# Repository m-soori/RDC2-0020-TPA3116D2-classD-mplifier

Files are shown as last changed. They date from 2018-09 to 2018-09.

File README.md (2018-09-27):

<p><a href="https://static.chipdip.ru/lib/954/DOC002954994.jpg" class="galery">Схема</a></p>

<p>Усилитель НЧ собран на микросхеме TPA3116D2.</p>
<p><a href="https://static.chipdip.ru/kits/9000398391/sh.png" class="galery">Схема</a></p>
<h2>Технические характеристики.</h2>
<p>Мощность на нагрузке 4 Ом. при U пит. 21В. – 2 x 50 Вт. (BTL), 100 Вт. (PBTL)<br/>Уровень сигнала на входе. - 0,8 … 2В.<br/>Отношение сигнал/шум. - 102 dB<br/>Коэффициент гармоник на половине мощности 25Вт. -  0,1%<br/>Напряжение питания – 4,5 В … 26 В.</p>
<p>Схема позволяет включать микросхему в двух режимах: </p>
<p>1. Мостовой BTL. В этом включении можно получить 2 канала по 50 Вт.<br/>2. Параллельно – мостовой (PBTL). Так как в этом режиме два канала BTL включены ещё и параллельно, то на выходе получаем один канал с удвоенной мощностью – 100 Вт.</p>
<p>На схемах ниже показаны все необходимые изменения для обоих режимов. </p>
<p>1. Подготовка платы для работы в мостовом режиме. Стерео 50 Вт.<br/>Собранный усилитель работает в мостовом режиме. Но если вы подаете на него сигнал по не симметричной линии, установите перемычки P7 и P12. Больше никаких перемычек устанавливать не надо. </p>
<p>2. Подготовка платы для работы в параллельно-мостовом режиме. Один канал 100 Вт.<br/>Установите перемычки P14, P15 и соедините перемычкой выходы усилителя P3 с P4 и P8 с P11.<br/>Теперь ваш усилитель будет работать в параллельно-мостовом режиме и выдавать 100 Вт.  Громкоговоритель подключайте к P6 и P8. Сигнал подавайте на вход правого канала.</p>
<p>Режим BTL</p>
<p><a href="https://static.chipdip.ru/kits/9000398391/BTL.png" class="galery">Схема BTL</a></p>
<p>Режим PBTL</p>
<p><a href="https://static.chipdip.ru/kits/9000398391/PBTL.png" class="galery">Схема PBTL</a></p>
<p>Подбором резисторов R5 и R8 можно подобрать уровень усиления и входное сопротивление, а также перевести усилитель в режимы ведущего (master) или ведомого (slave)</p>
<p><a href="https://static.chipdip.ru/kits/9000398391/tabR.png" class="galery">Настройка</a></p>
<p>Усилитель имеет очень высокий КПД > 90%, поэтому он не очень требователен к теплоотводу. В качестве радиатора можно использовать, <a href="/product0/9000398392" class="link">например этот</a>. Форма, крепежные отверстия и размеры, которого сделаны специально для этого модуля. К тому же он имеет золотое покрытие, что внешне очень привлекательно.</p>
<p>Радиатор</p>
<p><a href="https://static.chipdip.ru/kits/9000398391/RDC1-0021.jpg" class="galery">RDC1-0021</a></p>
<p>Это открытый проект! Лицензия, под которой он распространяется – <a href="https://creativecommons.org/licenses/by-sa/3.0/"  class="link">Creative Commons - Attribution - Share Alike</a> license.</p>

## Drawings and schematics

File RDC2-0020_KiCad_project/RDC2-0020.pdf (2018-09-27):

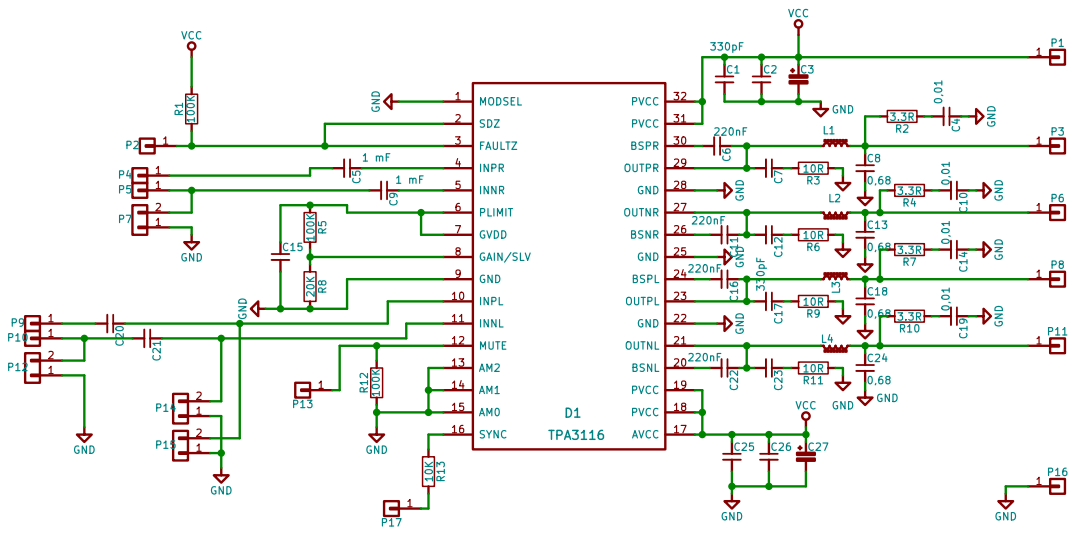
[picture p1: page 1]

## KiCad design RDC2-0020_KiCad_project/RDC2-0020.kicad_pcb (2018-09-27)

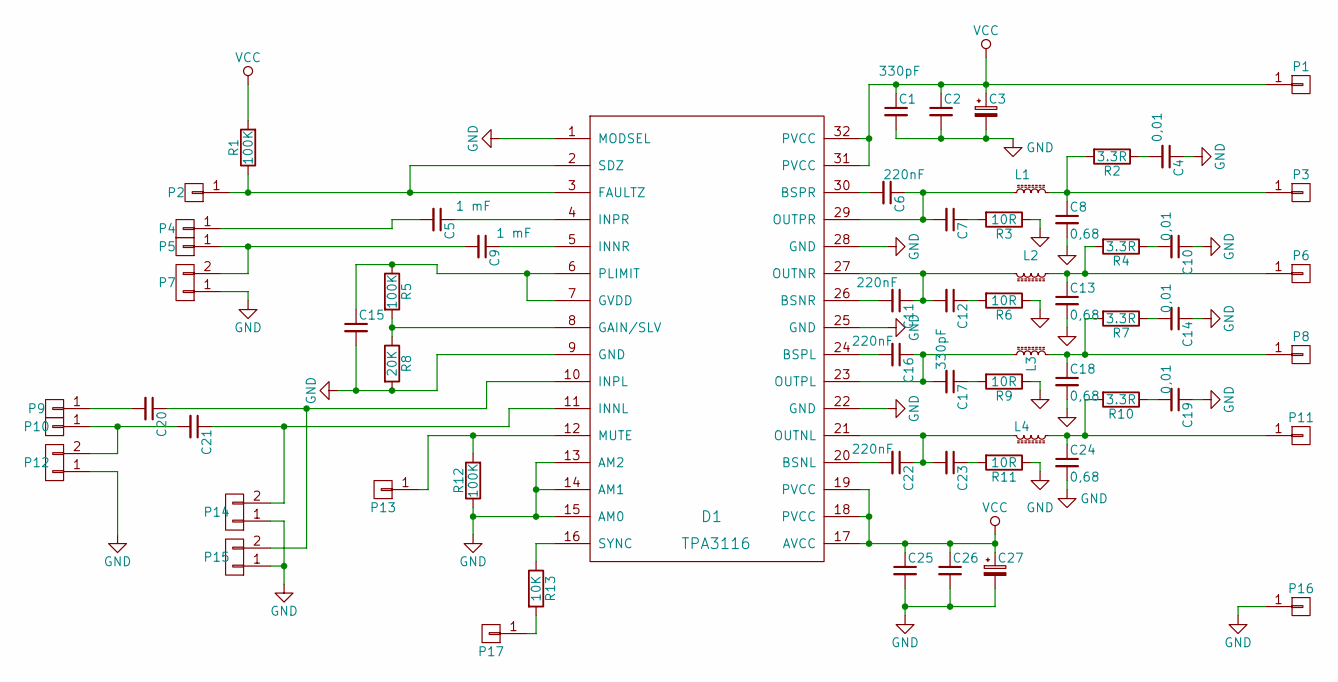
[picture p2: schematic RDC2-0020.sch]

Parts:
C1, C7, C12, C17, C23, C25: 330pF; C_1206
C2, C26: 0,1; C_0603
C3: 220mF; C_Radial_D8_L11.5_P3.5
C4, C10, C14, C19: 0,01; C_0805
C5, C9: 1 mF; C_0603
C6, C11, C16, C22: 220nF; C_0805
C8, C13, C18, C24: 0,68; C_1206
C15: C_Small; C_0805
C20, C21: C_Small; C_0603
C27: 220pF; C_Radial_D8_L11.5_P3.5
D1: TPA3116; TSSOP32
L1, L2, L3, L4: L_Core_Ferrite_Small; IND_12x12mm_h6mm
P1, P16: CONN_01X01; MountingHole_3.2mm_M3_Pad
P2, P3, P4, P5, P6, P8, P9, P10, P11, P13, P17: CONN_01X01; Pin_Header_Straight_1x01
P7, P12, P14, P15: CONN_01X02; JUMPER_ON
R1, R5, R12: 100K; R_0603
R2, R4, R7, R10: 3.3R; R_0603
R3, R6, R9, R11: 10R; R_0603
R8: 20K; R_0603
R13: 10K; R_0603

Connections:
GND: C1.2, C2.2, C3.2, C4.1, C8.2, C10.1, C13.2, C14.1, C15.2, C18.2, C19.1, C24.2, C25.2, C26.2, C27.2, D1.1 (MODSEL), D1.9 (GND), D1.13 (AM2), D1.14 (AM1), D1.15 (AM0), D1.22 (GND), D1.25 (GND), D1.28 (GND), P7.1, P12.1, P14.1, P15.1, P16.1, R3.1, R6.1, R8.2, R9.1, R11.1, R12.1
unnamed: C4.2, R2.1
unnamed: C5.1, D1.4 (INPR)
unnamed: C5.2, P4.1
unnamed: C6.1, C7.2, D1.29 (OUTPR), L1.1
unnamed: C6.2, D1.30 (BSPR)
unnamed: C7.1, R3.2
unnamed: C8.1, L1.2, P3.1, R2.2
unnamed: C9.1, D1.5 (INNR)
unnamed: C9.2, P5.1, P7.2
unnamed: C10.2, R4.1
unnamed: C11.1, C12.2, D1.27 (OUTNR), L2.2
unnamed: C11.2, D1.26 (BSNR)
unnamed: C12.1, R6.2
unnamed: C13.1, L2.1, P6.1, R4.2
unnamed: C14.2, R7.1
unnamed: C15.1, D1.6 (PLIMIT), D1.7 (GVDD), R5.1
unnamed: C16.1, C17.2, D1.23 (OUTPL), L3.1
unnamed: C16.2, D1.24 (BSPL)
unnamed: C17.1, R9.2
unnamed: C18.1, L3.2, P8.1, R7.2
unnamed: C19.2, R10.1
unnamed: C20.1, D1.10 (INPL), P15.2
unnamed: C20.2, P9.1
unnamed: C21.1, D1.11 (INNL), P14.2
unnamed: C21.2, P10.1, P12.2
unnamed: C22.1, C23.2, D1.21 (OUTNL), L4.2
unnamed: C22.2, D1.20 (BSNL)
unnamed: C23.1, R11.2
unnamed: C24.1, L4.1, P11.1, R10.2
unnamed: D1.2 (SDZ), D1.3 (FAULTZ), P2.1, R1.1
unnamed: D1.8 (GAIN/SLV), R5.2, R8.1
unnamed: D1.12 (MUTE), P13.1, R12.2
unnamed: D1.16 (SYNC), R13.1
unnamed: P17.1, R13.2
VCC: C1.1, C2.1, C3.1, C25.1, C26.1, C27.1, D1.17 (AVCC), D1.18 (PVCC), D1.19 (PVCC), D1.31 (PVCC), D1.32 (PVCC), P1.1, R1.2

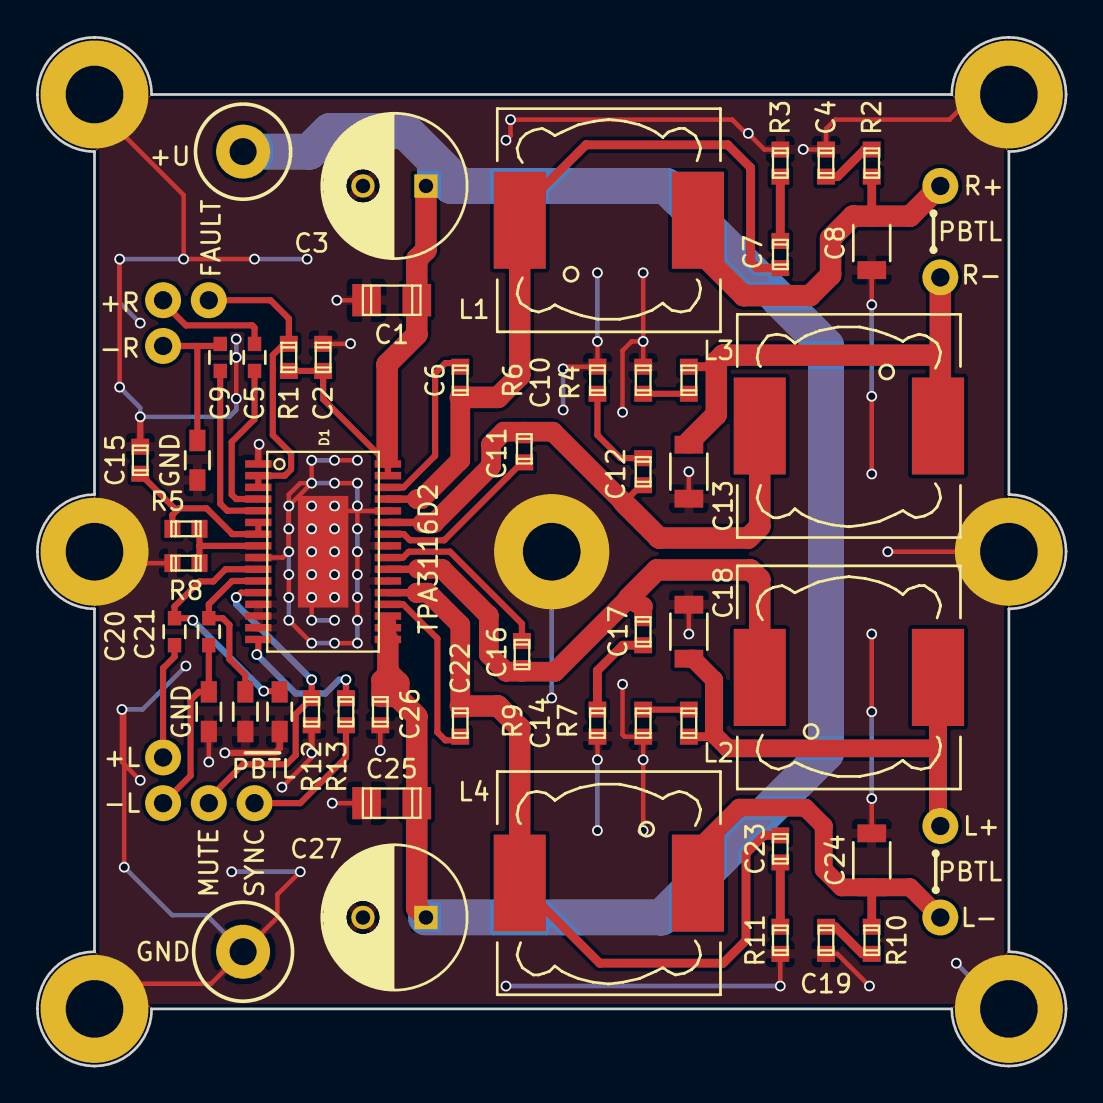
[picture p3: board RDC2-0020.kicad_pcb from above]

Board: 2 copper layers, 57.2 x 57.2 mm, 62 parts (0 on the bottom side), 36 nets.

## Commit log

2018-09-27 KiCad project
    [RDC2-0020.kicad_pcb, RDC2-0020.sch]
2018-09-27 Gerber files
    [RDC2-0020-B.Cu.gbr, RDC2-0020-B.Mask.gbr, RDC2-0020-B.SilkS.gbr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]
